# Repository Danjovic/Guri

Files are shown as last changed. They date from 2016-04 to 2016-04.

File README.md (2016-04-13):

# Guri
Ignition controller for VW air cooled engines.

Volkswagen air cooled engines have been produced over 70 years and millions of them still in use today pushing beetles, buses and even small aircraft. Such engines cheap and easy to maintain yet their outdated design provides space for a lot of hacking. 

The present project addresses a small but important improvement in the engine by the control of coil charging time and providing constant time for burning the fuel mixture allover the engine RPM range.

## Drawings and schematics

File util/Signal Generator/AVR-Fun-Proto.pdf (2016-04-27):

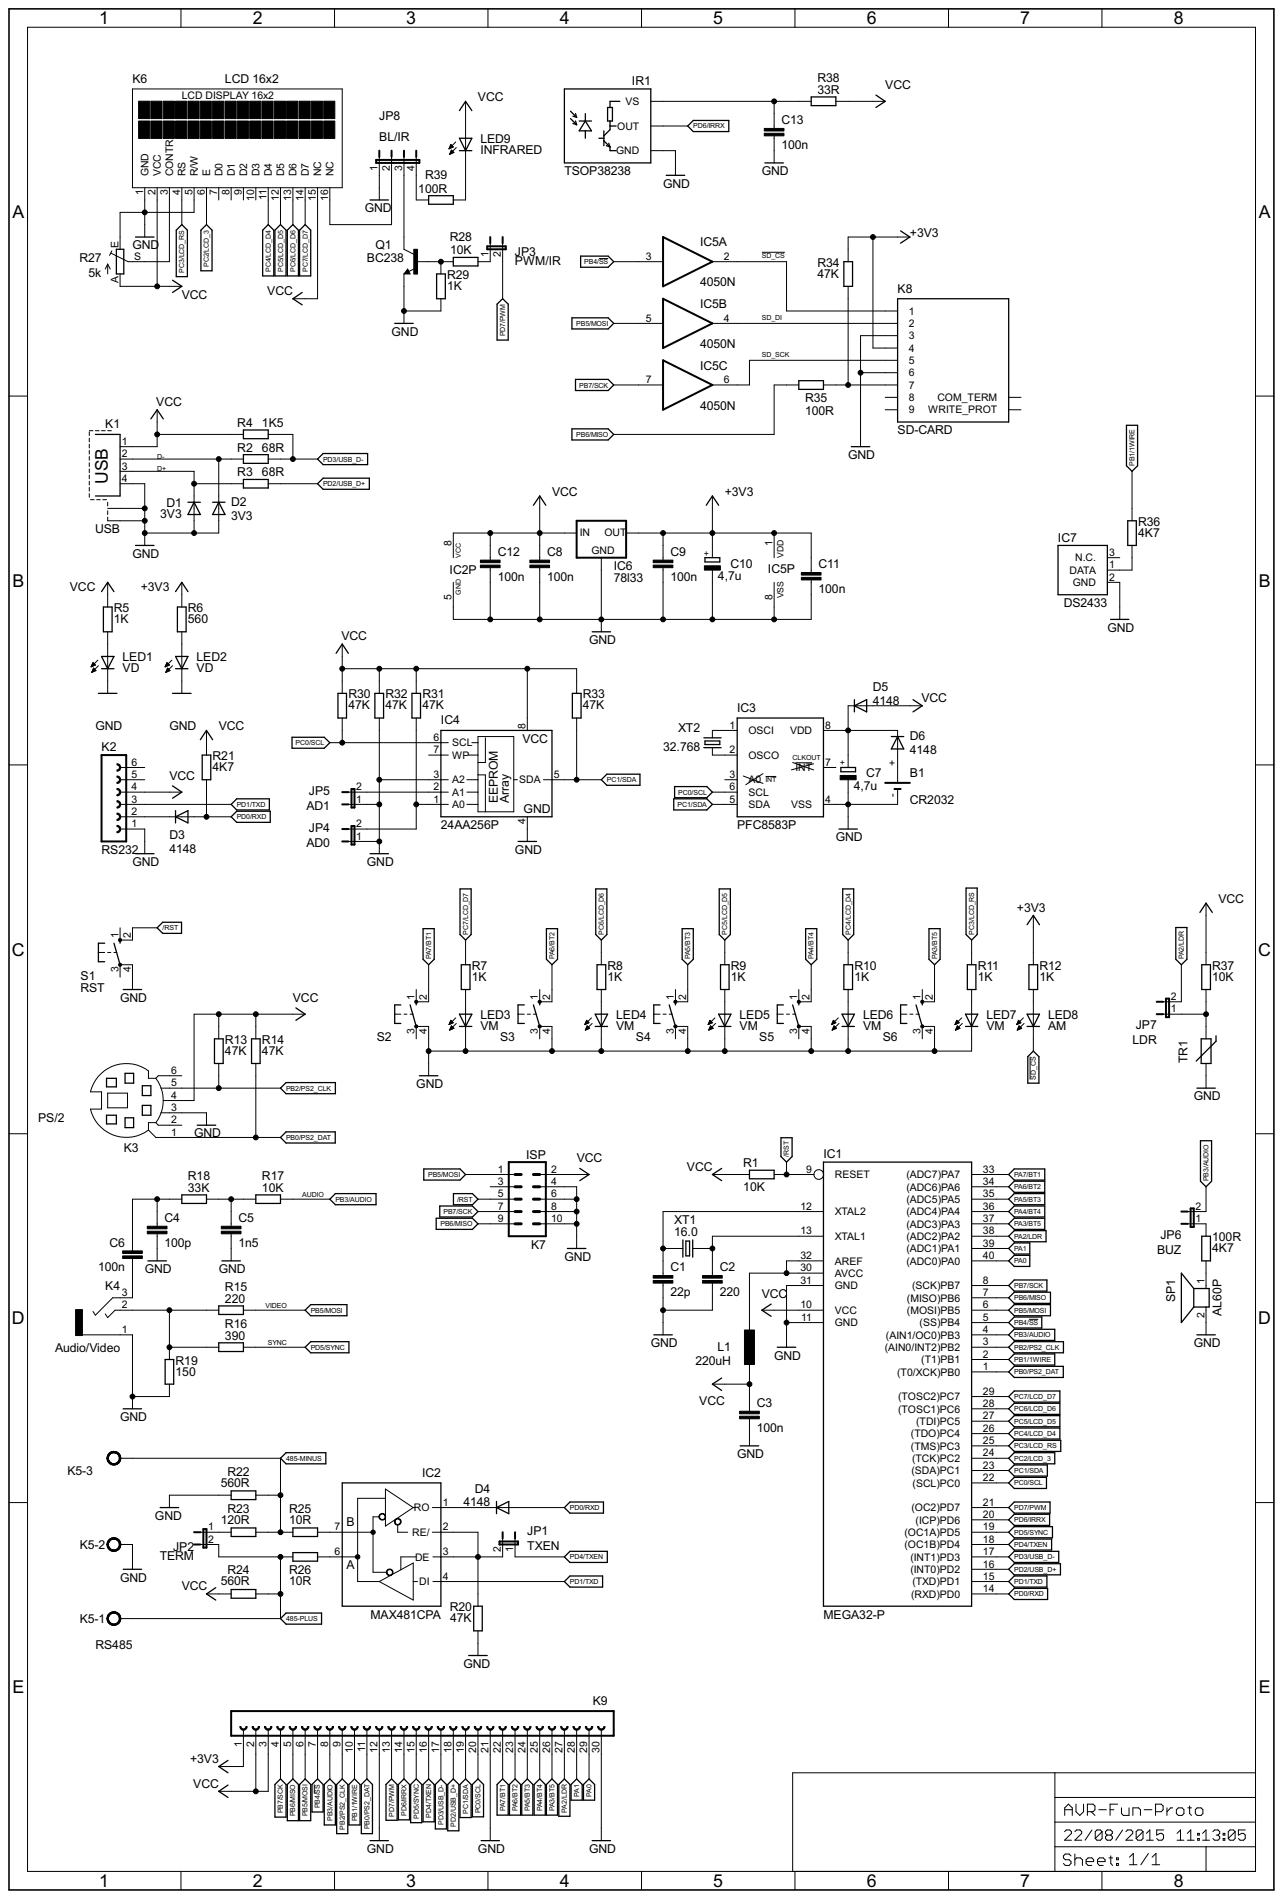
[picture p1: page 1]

1 | PD0/RXD

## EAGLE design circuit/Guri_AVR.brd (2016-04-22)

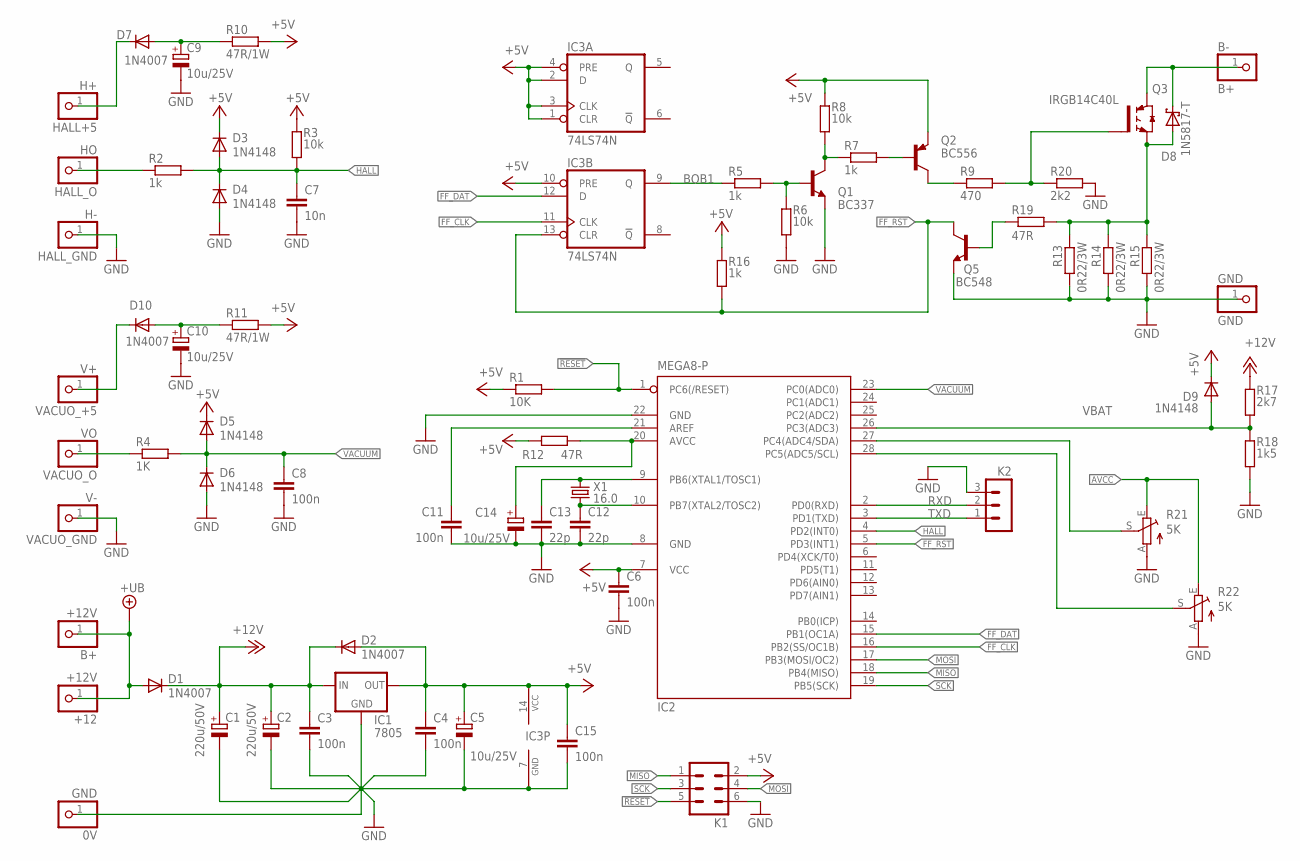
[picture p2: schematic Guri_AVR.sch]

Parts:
0V: GND; 1X01
+12: +12V; 1X01
B+: +12V; 1X01
B-: B+; 1X01
C1, C2: 220u/50V; E5-10,5
C3, C4, C6, C8, C11, C15: 100n; C050-025X075
C5, C9, C10, C14: 10u/25V; E2-5
C7: 10n; C050-025X075
C12, C13: 22p; C050-024X044
D1, D2, D7, D10: 1N4007; D-7.5
D3, D4, D5, D6, D9: 1N4148; DO35-7
D8: 1N5817-T; DO41-7.6
GND: GND; 1X01
H+: HALL+5; 1X01
H-: HALL_GND; 1X01
HO: HALL_O; 1X01
IC1: 7805; 78XXS
IC2: MEGA8-P; DIL28-3
IC3: 74LS74N; DIL14
K1: ML6
K2: MA03-1
Q1: BC337; TO92-EBC
Q2: BC556; TO92-EBC
Q3: IRGB14C40L; TO262-V
Q5: BC548; TO92-EBC
R1: 10K; 0207/7L
R2, R5, R7, R16: 1k; 0207/7L
R3, R6, R8: 10k; 0207/7L
R4: 1K; 0207/7L
R9: 470; 0207/7L
R10, R11: 47R/1W; 0207/7L
R12, R19: 47R; 0207/7L
R13, R14, R15: 0R22/3W; 0309/10
R17: 2k7; 0207/7L
R18: 1k5; 0207/7L
R20: 2k2; 0207/7L
R21, R22: 5K; ECP10P
V+: VACUO_+5; 1X01
V-: VACUO_GND; 1X01
VO: VACUO_O; 1X01
X1: 16.0; HC49/S

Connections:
!RESET: IC2.1 (PC6(/RESET)), K1.5, R1.4 (2)
+5V: C4.1, C5.+, C6.1, C15.1, D2.A, D3.C, D5.C, D9.C, IC1.OUT, IC2.7 (VCC), IC3.1 (CLR), IC3.2 (D), IC3.3 (CLK), IC3.4 (PRE), IC3.10 (PRE), IC3.14 (VCC), K1.2, Q2.E, R1.3 (1), R3.4 (2), R8.4 (2), R10.4 (2), R11.4 (2), R12.4 (2), R16.4 (2)
+12V: C1.+, C2.+, C3.1, D1.C, D2.C, IC1.IN, R17.3 (1)
+UB: +12.1, B+.1, D1.A
AREF: C11.1, IC2.21 (AREF)
AVCC: C14.+, IC2.20 (AVCC), R12.3 (1), R21.E, R22.E
BOB1: IC3.9 (Q), R5.3 (1)
FF_CLK: IC2.16 (PB2(SS/OC1B)), IC3.11 (CLK)
FF_DAT: IC2.15 (PB1(OC1A)), IC3.12 (D)
FF_RST: IC2.5 (PD3(INT1)), IC3.13 (CLR), Q5.C, R16.3 (1)
GND: 0V.1, C1.-, C2.-, C3.2, C4.2, C5.-, C6.2, C7.2, C8.2, C9.-, C10.-, C11.2, C12.2, C13.2, C14.-, C15.2, D4.A, D6.A, GND.1, H-.1, IC1.GND, IC2.8 (GND), IC2.22 (GND), IC3.7 (GND), K1.6, K2.3, Q1.E, Q5.E, R6.3 (1), R13.1, R14.1, R15.1, R18.4 (2), R20.4 (2), R21.A, R22.A, V-.1
HALL: C7.1, D3.A, D4.C, IC2.4 (PD2(INT0)), R2.4 (2), R3.3 (1)
HALL_IN: HO.1, R2.3 (1)
MISO: IC2.18 (PB4(MISO)), K1.1
MOSI: IC2.17 (PB3(MOSI/OC2)), K1.4
unnamed: C9.+, D7.A, R10.3 (1)
unnamed: D10.C, V+.1
unnamed: Q2.B, R7.4 (2)
unnamed: Q1.C, R7.3 (1), R8.3 (1)
unnamed: Q1.B, R5.4 (2), R6.4 (2)
unnamed: C10.+, D10.A, R11.3 (1)
unnamed: D7.C, H+.1
unnamed: Q2.C, R9.3 (1)
unnamed: Q3.1 (G), R9.4 (2), R20.3 (1)
unnamed: B-.1, D8.C, Q3.2 (C)
unnamed: C13.1, IC2.9 (PB6(XTAL1/TOSC1)), X1.2
unnamed: C12.1, IC2.10 (PB7(XTAL2/TOSC2)), X1.1
unnamed: Q5.B, R19.4 (2)
unnamed: IC2.27 (PC4(ADC4/SDA)), R21.S
unnamed: IC2.28 (PC5(ADC5/SCL)), R22.S
unnamed: D8.A, Q3.3 (E), R13.2, R14.2, R15.2, R19.3 (1)
RXD: IC2.2 (PD0(RXD)), K2.2
SCK: IC2.19 (PB5(SCK)), K1.3
TXD: IC2.3 (PD1(TXD)), K2.1
VAC-IN: R4.3 (1), VO.1
VACUUM: C8.1, D5.A, D6.C, IC2.23 (PC0(ADC0)), R4.4 (2)
VBAT: D9.A, IC2.26 (PC3(ADC3)), R17.4 (2), R18.3 (1)

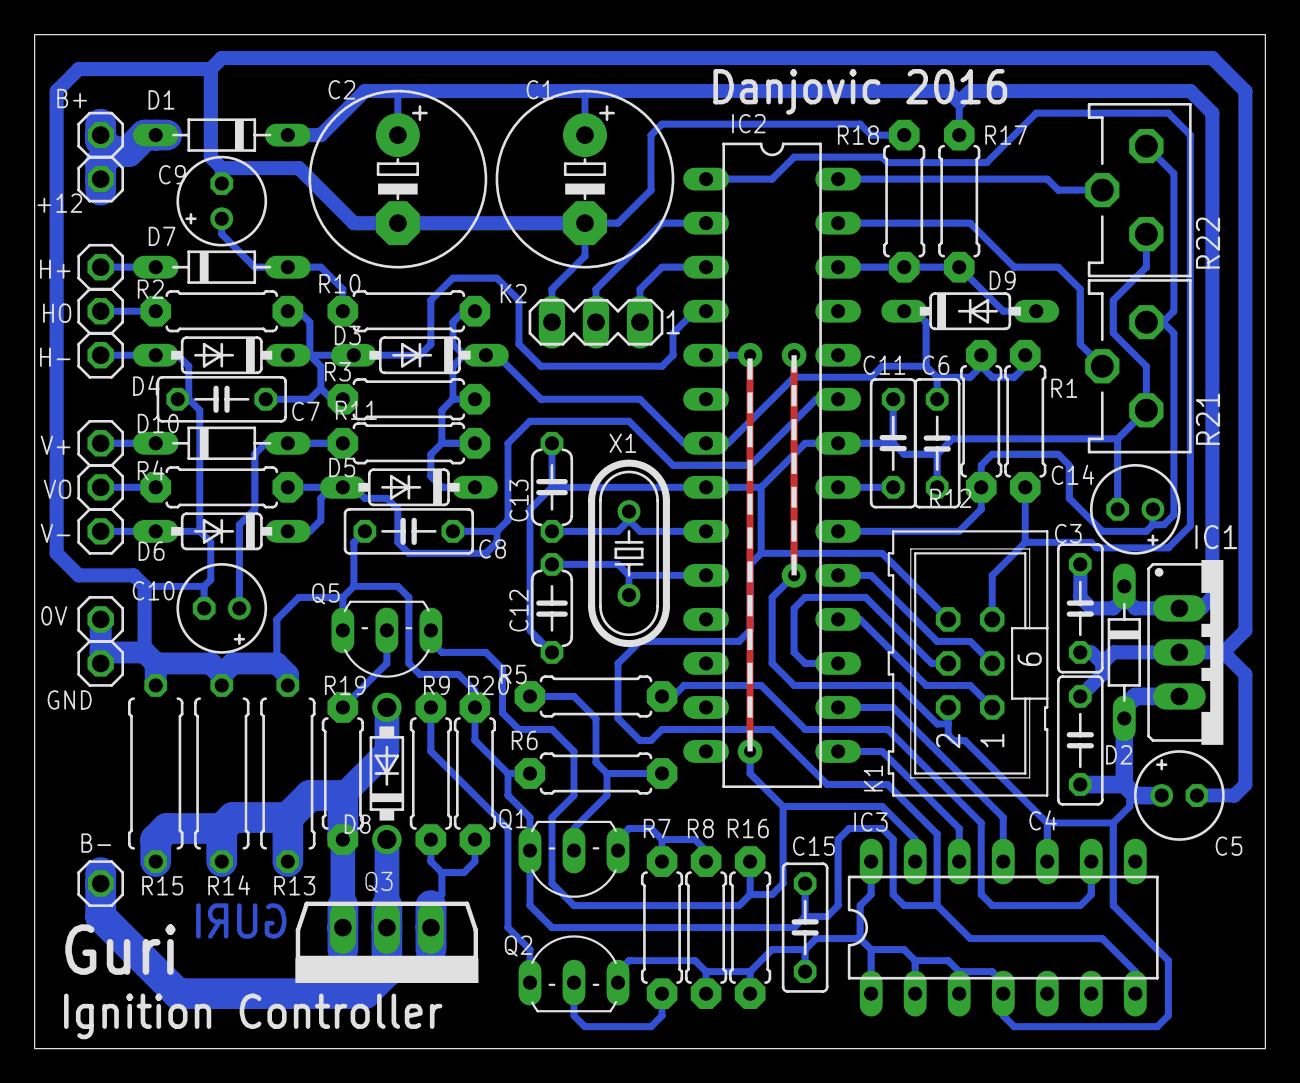
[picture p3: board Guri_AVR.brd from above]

Board: 2 copper layers, 71.0 x 58.5 mm, 68 parts (0 on the bottom side), 37 nets.

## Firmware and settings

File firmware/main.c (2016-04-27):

/*
   Guri: Ignition Timing Controller for VW Air Cooled engines
   
   Danjovic 2016 - Danjovic@hotmail.com
 

                    ATMega8
                   +---_---+  
        nRESET/PC6-|1    28|- PC5/ADC5/SCL - POT2
   DEBUG - RXD/PD0-|2    27|- PC4/ADC4/SDA - POT1
   DEBUG - TXD/PD1-|3    26|- PC3/ADC3 - VBAT
 IGNTSTS -INT0/PD2-|4    25|- PC2/ADC2
 OVERCUR  INT1/PD3-|5    24|- PC1/ADC1
        XCK\T0/PD4-|6    23|- PC0/ADC0 - VACUUM
               VCC-|7    22|- GND 
               GND-|8    21|- AREF
           XT1/PB6-|9    20|- AVCC
           XT2/PB7-|10   19|- PB5/SCK
            T1/PD5-|11   18|- PB4/MISO
          AIN0/PD6-|12   17|- PB3/MOSI/OC2
          AIN1/PD7-|13   16|- PB2/nSS/OC1B - FF_CLK
          ICP1/PB0-|14   15|- PB1/OC1A - FF_DAT
                   +-------+
   
*/

#define DEBUG

// *******************************Libraries************************
#include <avr/io.h>
#include <avr/pgmspace.h>
#include <avr/interrupt.h>
#include <inttypes.h>
#include <util/delay.h>
#include <avr/wdt.h> 

#ifdef DEBUG
#include <stdio.h>
#include "uart.h"
#include "uart.c"

#endif
// *******************************Definitions**********************
#define FF_CLK (1<<PB2)
#define FF_DAT (1<<PB1)

//


//F_CPU 12000000

#define TIME_FACTOR 64000000UL/F_CPU  // us
#define RPM_FACTOR  7500000UL
#define MIN_RPM      150
#define MAX_RPM     6200

#define _t_max_rpm  RPM_FACTOR/MAX_RPM     
#define _t_min_rpm  62500    //  120 RPM
#define _t_base     2000 / TIME_FACTOR // 2ms
#define _t_burn     500 / TIME_FACTOR  // 0,5ms 

#define _v_8V       114   // ADC reading for 8Volts
#define _v_15V      214   // ADC reading for 15Volts
#define _delta_Vbat ( _v_15V - _v_8V ) // delta


#define _v_127mmHg       114   // ADC reading for 127.5 mmHg
#define _v_270mmHg      214   // ADC reading for 270 mmHg
#define _delta_Vacuum ( _v_270mmHg - _v_127mmHg ) // delta


#define _v_factor      8    // Multiply factor to reduce loss of bits
                         // in the interpolation
#define _v_interval    15   // ending interval 


// *******************************Variables************************
static volatile uint8_t Vbat=0;
static volatile uint8_t Vacuum=0;


const uint16_t PROGMEM Tcharge[16] = { 600,575,550,525,500,475,450,425,400,375,350,325,300,275,250,225 };
const uint16_t PROGMEM Tvacuum[16] = {   0, 25, 50, 75,100,125,150,175,200,225,250,275,300,325,350,375 };
//const uint16_t PROGMEM constants[] = {_t_max_rpm, _t_min_rpm, _t_base, _t_burn } ;

// *******************************Function Prototypes**************
void init_hw(void);
uint16_t read_adc(uint8_t channel);


// *******************************Main Loop************************
int main (void) {

	uint8_t v;
	uint16_t temp16;

	init_hw();      // Initialize hardware
	                // Initialize variables
#ifdef DEBUG
	uart_init();    // Initialize USART, 19200 8N1
    stdout = &uart_output;
    stdin  = &uart_input;
	printf_P(PSTR("Guri:Debug mode\n"));
			   
#endif			   


    while(1) {
        puts("Press a Key");
        v = getchar();
		temp16=read_adc(0); printf("vacuum: %u\n",temp16);  
		temp16=read_adc(3); printf("vbat  : %u\n",temp16);  
		temp16=read_adc(4); printf("pot1  : %u\n",temp16);  
		temp16=read_adc(5); printf("pot2  : %u\n",temp16); 
 		
    }
		   
		   
			   
	//sei();     // start interrupts
	
	wdt_reset();
	wdt_disable();
	wdt_enable(WDTO_500MS);
	
	for (;;) {
		// reset watchdog
		wdt_reset();
		
		// read Vbat
		ADCSRA &= ~7; // select channel 0 (VBAT)
		ADCSRA |= ADSC; // start conversion
		while  	bit_is_set(ADCSRA, ADSC); // wait end of conversion
		v = ADCH; // read Battery voltage
		if (v < _v_8V ) v  =  _v_8V;  // low value limit
		if (v > _v_15V ) v = _v_15V;  // high value limit
		// convert value into index to lookup table		
		temp16 = (v - _v_8V) * ( _v_factor * _v_interval);
		temp16 = temp16 / (_v_factor * _delta_Vbat);
		v = (uint8_t)temp16;
		Vbat = v;
		
	
		// read Vaccum sensor
		ADCSRA |= 1; // select channel 1 (VACUUM)
		ADCSRA |= ADSC; // start conversion
		while  	bit_is_set(ADCSRA, ADSC); // wait end of conversion
		v = ADCH; // read vacuum at Manifold	
		if (v < _v_127mmHg ) v  =  _v_127mmHg;  // low value limit
		if (v > _v_270mmHg ) v = _v_270mmHg;  // high value limit
		// convert value into index to lookup table
		temp16 = (v - _v_127mmHg) * ( _v_factor * _v_interval);
		temp16 = temp16 / (_v_factor * _delta_Vacuum);
		v = (uint8_t)temp16;		
		Vacuum = v;
		
	}

}

// ******************************Initialize Hardware***************
void init_hw(void){
	
	// Initialize I/O
	DDRB = (FF_CLK | FF_DAT);
	PORTB = 0;
	PORTB |= FF_CLK;  // pulse clock to turn off coil 
	PORTB = 0;
	
	// Initialize ADC
	ADMUX =  (1<<REFS0); // Aref=AVcc
	ADCSRA=(1<<ADEN)|(1<<ADPS2)|(1<<ADPS1)|(1<<ADPS0); //Prescalar div factor =128
  
	
	// Initialize Timer
	TCCR1A=0;          // Timer 1 in Normal mode, OC1A/B disconnected
	TCNT1  = 0;        // Clear Timer1
	TCCR1B=(3<CS10);   // Prescaler 64, overflow 262ms
	
	// Initialize Interrupts
	TIMSK = (1<<TOIE1) + (1<<OCIE1A) + (1<<OCIE1B) ;// Overflow, compare A and B
	MCUCR = (3<<ISC01);// INT0 on rising edge
	GICR  = (1<<INT0); // INT0  
	//sei();
}

// ******************************Perform one Analog reading********
uint16_t read_adc(uint8_t channel) {
		ADMUX &= ~7;     //clear 3 lsb from channel selection
		ADMUX |= ( channel & 7); // range check in argument
		ADCSRA |= (1<<ADSC); // start conversion
		while  	bit_is_set(ADCSRA, ADSC); // wait end of conversion
		return ADC; // read Battery voltage, 8 bits
}

// ******************************Timer 1 Overflow******************
ISR (TIMER1_OVF_vect) {
	
	PORTB &= ~FF_DAT;   // Turn off coil and timers
	asm ("nop");		
	PORTB |= FF_CLK;
	asm ("nop");
	PORTB &= ~FF_CLK;
	
	TCCR1B = 0;           // Stop Timer1
	TCNT1  = 0;           // Clear Timer1
	
	TIMSK = (1<<TOIE1);	// Disable compare interrupts
}

// ******************************Timer 1 Compare A*****************
ISR (TIMER1_COMPA_vect) {     // Start Charging the Coil 
	PORTB |= FF_DAT;
	asm ("nop");	
	PORTB |= FF_CLK;
	asm ("nop");
	PORTB &= ~FF_CLK;
}

// ******************************Timer 1 Compare B*****************
ISR (TIMER1_COMPB_vect) {     // Stop Charge, generate Spark
	PORTB &= ~FF_DAT;
	asm ("nop");	
	PORTB |= FF_CLK;
	asm ("nop");
	PORTB &= ~FF_CLK;
}

// ******************************External Interrupt****************
ISR (INT0_vect) {             // Measure Tcycle
	uint16_t t_cycle=TCNT1;
	TCNT1=0;
	TCCR1B=(3<CS10);   // (re)start timer, Prescaler 64	
	
	PORTB &= ~FF_DAT;  // turn off coil if we reach here 
	asm ("nop");	   // before Compare B interrupt
	PORTB |= FF_CLK;
	asm ("nop");
	PORTB &= ~FF_CLK;
	
	
	// Check if RPM is valid. This function has a side effect of
	// limiting maximum RPM by not programming a spark either on 
	// too high or too low engine speeds
	if ((t_cycle > _t_max_rpm) && (t_cycle < _t_min_rpm) ) { 
	
		// compute spark time
		t_cycle -= _t_base ;                    // base time
		t_cycle -= pgm_read_word (&Tvacuum[Vacuum]); // vaccum advance time
		OCR1B = t_cycle;
		
		// compute Start of charge time but leave room for the mixture 
		// to burn. This may reduce coil charging time.
		t_cycle -= pgm_read_word(&Tcharge[Vbat]);  // compute charge time
		if (t_cycle < _t_burn) t_cycle = _t_burn; // leave room
		OCR1A = t_cycle;
		
		// (re)program compare interrupts
		TIMSK = (1<<TOIE1) + (1<<OCIE1A) + (1<<OCIE1B) ;
		
	} else { 
		// Disable compare interrupts
		TIMSK = (1<<TOIE1);
	}	

}

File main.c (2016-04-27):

/* Name: main.c
 * Project: Avr-Fun base project
 * Author: Daniel Jose Viana
 * Creation Date: 13/08/2015
 * Tabsize: 4	
 * Copyright: (c) 2007 by Daniel Jose Viana
 * License: GNU GPL v2 (see License.txt)
 * This Revision: 
 */

#include <avr/io.h>
#include <avr/pgmspace.h>
#include <avr/interrupt.h>
#include <util/delay.h>
#include <stdio.h>

#include "bsp.h"



///////////////////////////////////////////
///

#define SNES_CLOCK   (1<<PB1)  // Pino CLOCK mantido em nível baixo para gerar sinal latch
                              // atraves de rede rc. Shift ocorre em pulsos de clock rapidos 
#define SNES_DATA    (1<<PB7)
 
#define SNES_CLOCK_LOW()	PORTB &= ~(SNES_CLOCK);
#define SNES_CLOCK_HIGH()	PORTB |= SNES_CLOCK;
#define SNES_GET_DATA()		(PINB & SNES_DATA)

#define MAX_REPORTS 4  // 4 gamepads 
#define REPORT_SIZE 3  // Size of report: ID + 2 bytes of data

#define uchar uint8_t
#define MAX_RPM 7000
#define MIN_RPM 150

static int16_t RPM=900;

ISR (TIMER1_COMPA_vect ) {
	PORTB |= (1<<3);
}

ISR (TIMER1_COMPB_vect ) {
	PORTB &= ~(1<<3);
}


void	show_RPM(uint16_t rpm){
	char st[6];
	
	LCD_puts ("\fRPM:\0");
	LCD_puts (itoa(rpm,st,10));
//	LCD_putc ("-");
//	LCD_puts (itoa((uint16_t)(7500000/rpm),st,10));
	
}

void add_RPM (int16_t incr_rpm){
	uint16_t T1_top,T1_mid;
	
	if (incr_rpm ==0)
		RPM=900;
	else 
		RPM += incr_rpm;
		
	if (RPM>MAX_RPM) RPM=MAX_RPM;
	if (RPM<MIN_RPM) RPM=MIN_RPM;
	

    show_RPM (RPM);


	T1_top = (uint16_t)(7500000/RPM);
	T1_mid = (uint16_t)(2500000/RPM);
	
	cli(); 
	// Stop Timer1
		TCCR1B = (1<<WGM12);
	TCNT1 = 0;
	
	// Change values
	OCR1A = T1_top;
	OCR1B = T1_mid;
	
	// Restart Timer1
	TCCR1B = (1<<WGM12) | (1<<CS11) | (1<<CS10) ;
	TCNT1 = 0;
	
	TIFR = (1<<OCF1A) | (1<<OCF1B); // clear any pending interrupts
	
	sei();
	
	
	
}
	
int main (void) {


	uint8_t tb1,tb2,tb3,tb4,tb5=0;
	
	
	// Setup output pin (PB3)
	DDRB |= (1<<3);
	PORTB &= ~(1<<3);
	
	// Setup Timer1, prescaler 64, CTC mode
	TCCR1A = 0;
	TCCR1B = (1<<WGM12) | (1<<CS11) | (1<<CS10) ;
	TCNT1 = 0;
	
	TIMSK = (1<<OCIE1A) | (1<<OCIE1B);
	
	
	
	LCD_Init();
    add_RPM(0);
	show_RPM(RPM);
	sei();
	
	
	// Main loop
	for (;;) {
		// action for button 1
		if (Read_Button(BUTTON1)) {
			if (tb1<255) tb1++;
		
		} else { // release
			if (tb1 > 10) {
				add_RPM(-100);
			}
			tb1=0;
		}

		// action for button 2
		if (Read_Button(BUTTON2)) {
			if (tb2<255) tb2++;
		
		} else { // release
			if (tb2 > 10) {
				add_RPM(-50);
			}
			tb2=0;
		}

		// action for button 3
		if (Read_Button(BUTTON3)) {
			if (tb3<255) tb3++;
		
		} else { // release
			if (tb3 > 10) {
				add_RPM(0);  // set 900 RPM 
			}
			tb3=0;
		}

		// action for button 4
		if (Read_Button(BUTTON4)) {
			if (tb4<255) tb4++;
		
		} else { // release
			if (tb4 > 10) {
				add_RPM(50);
			}
			tb4=0;
		}

		// action for button 5
		if (Read_Button(BUTTON5)) {
			if (tb5<255) tb5++;
		
		} else { // release
			if (tb5 > 10) {
				add_RPM(100);
			}
			tb5=0;
		}
	
		_delay_ms(10);
	
	
	}



}

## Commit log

2016-04-18 Preliminary schematic & PCB
    Preliminary schematic and printed circuit board
    [Guri_AVR.brd, Guri_AVR.sch]
2016-04-22 New layout for preliminary board
    [Guri_AVR.brd, Guri_AVR.sch]
2016-04-27 organizing of file tree
    [Guri_AVR.brd, Guri_AVR.old.brd, Guri_AVR.old.sch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]
